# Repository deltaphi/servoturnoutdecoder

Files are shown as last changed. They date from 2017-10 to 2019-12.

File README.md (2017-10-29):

# Arudino Servo Decoder for the Motorola Protocol

* Motorola Input via INT0 (phase-correct)
* Control six Servos via the PWM outputs

# Dependencies

* Based on https://github.com/666c796e6e/LibMotorola/commit/a36dd47014a77b1eea2f04f38cabde1bba2f1c59
* Based on https://github.com/MicroBahner/MobaTools/commit/ad47b301049b6bf6d05046a2db197733567ed501

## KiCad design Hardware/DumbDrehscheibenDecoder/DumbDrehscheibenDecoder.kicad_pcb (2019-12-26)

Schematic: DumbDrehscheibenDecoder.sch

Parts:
A1: Arduino_Nano_v2.x; Arduino_Nano
C1: 470u; CP_Radial_D12.5mm_P5.00mm
D1, D2: D_Bridge_+-AA; Diode_Bridge_19.0x3.5x10.0mm_P5.0mm
D3: 1N4001; D_A-405_P7.62mm_Horizontal
H1, H2, H3, H4: MountingHole_Pad; MountingHole_3.2mm_M3_DIN965_Pad
J1, J2: Screw_Terminal_01x04; TerminalBlock_RND_205-00003_1x04_P5.00mm_Horizontal
R1, R3: 22k; R_Axial_DIN0204_L3.6mm_D1.6mm_P7.62mm_Horizontal
R2: 220; R_Axial_DIN0204_L3.6mm_D1.6mm_P7.62mm_Horizontal
SW1: SW_Push; SW_PUSH_6mm
U1: L293D; DIP-16_W7.62mm
U2: LTV-817; DIP-4_W7.62mm

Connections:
/MM_0: D1.4 (~~), D3.2, J2.2, U2.2
/MM_B: D1.3 (~~), J2.1, R1.2
/MM_Sense: A1.5 (D2), R2.1, U2.4
/MM_Vin: A1.30 (VIN), D1.1 (+)
/MOT_1Y: J1.4, U1.3
/MOT_2Y: J1.3, U1.6
/MOT_3Y: J1.1, U1.11
/MOT_4Y: J1.2, U1.14
/PWR_0: D2.4 (~~), J2.4
/PWR_B: D2.3 (~~), J2.3
/Pwr_Vin: D2.1 (+), U1.8
GND: A1.4 (GND), A1.29 (GND), C1.2, D1.2 (-), D2.2 (-), H1.1, H2.1, H3.1, H4.1, SW1.2, U1.4, U1.5, U1.12, U1.13, U2.3
unnamed: A1.6 (D3), U1.9
unnamed: A1.7 (D4), U1.7
unnamed: A1.8 (D5), U1.10
unnamed: A1.9 (D6), U1.1
unnamed: A1.10 (D7), U1.15
unnamed: A1.12 (D9), U1.2
unnamed: A1.19 (A0), R3.1, SW1.1
unnamed: D3.1, R1.1, U2.1
VCC: A1.27 (+5V), C1.1, R2.2, R3.2, U1.16

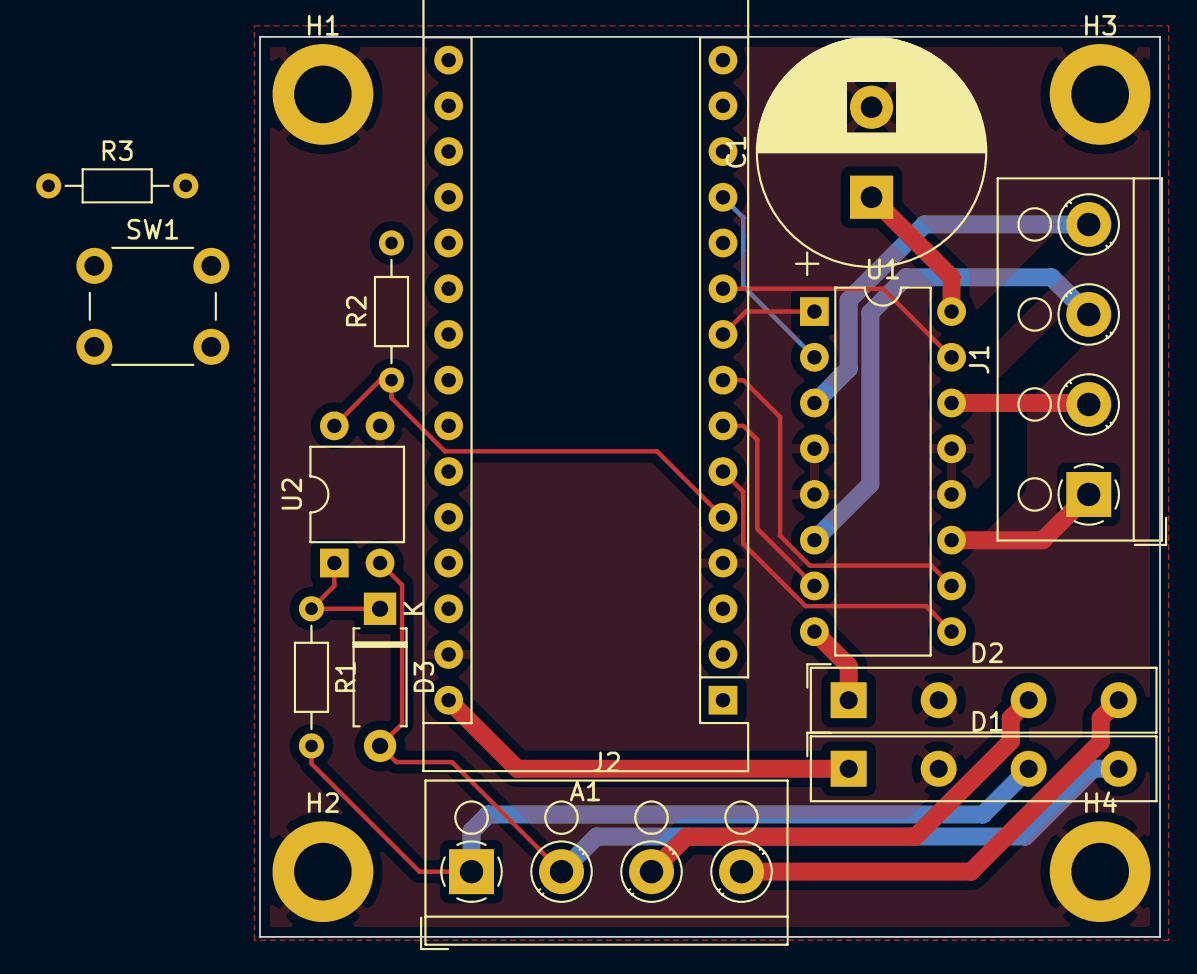
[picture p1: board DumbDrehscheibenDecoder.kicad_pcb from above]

Board: 2 copper layers, 50.0 x 50.0 mm, 17 parts (0 on the bottom side), 21 nets.

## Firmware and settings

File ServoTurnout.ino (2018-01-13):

#include <MobaTools.h>

#include <DataHandlerInterface.h>
#include <Decoder145027.h>
#include <Detect145027.h>

//Globally create a detector.
Detect145027 detector(Detect145027::TURNOUT_NOMINAL_PULSE_WIDTH_MICROS);
Decoder145027 decoder;

void handler() {

  //Do read the pin that corresponds to the interrupt as fast as possible.
  //This is machine-dependent!
  int fastReadResult = PIND & (1 << PD2);

  //Call the appropriate Method on the detector.
  if (fastReadResult != 0) {
    //state is up, must have been leading edge..
    detector.pickUpLeadingEdge();
  } else {
    //must have been trailing edge then...
    detector.pickUpTrailingEdge();
  }
}

constexpr long kRelayOnDuration_ms = 20; 

class ExampleDataHandler: public DataHandlerInterface {
public:
  const uint16_t address_;
  const uint8_t servo_pin;
  uint8_t red_angle;
  uint8_t green_angle;
  Servo8 servo_;
  int servo_pos;

  uint8_t polarize_red_pin;
  uint8_t polarize_green_pin;

  bool active = false;
  unsigned long lastActionTime;

  constexpr static uint8_t kServoSpeed = 10;

  enum TurnoutDirectionType {
    RED, GREEN
  };
  
  ExampleDataHandler(uint16_t address, uint8_t servo_pin, uint8_t red_angle, uint8_t green_angle, uint8_t polarize_red_pin, uint8_t polarize_green_pin):
    address_(address), servo_pin(servo_pin), 
    red_angle(red_angle), green_angle(green_angle),
    servo_pos(green_angle),
    polarize_red_pin(polarize_red_pin), polarize_green_pin(polarize_green_pin) {
  }

  ExampleDataHandler(uint16_t address, uint8_t servo_pin, uint8_t red_angle, uint8_t green_angle):
  address_(address), servo_pin(servo_pin),
  red_angle(red_angle), green_angle(green_angle),
  servo_pos(green_angle),
  polarize_red_pin(255), polarize_green_pin(255) {
  }

  void init() {
    servo_.attach(servo_pin, true);
    servo_.setSpeed(kServoSpeed);
    //updateServo();
    if (polarize_red_pin != 255) {
      pinMode(polarize_red_pin, OUTPUT);
      digitalWrite(polarize_red_pin, LOW);
    }
    if (polarize_green_pin != 255) {
      pinMode(polarize_green_pin, OUTPUT);
      digitalWrite(polarize_green_pin, LOW);
    }
  }

  /**
   * \brief Handle a MM message
   * 
   * \param address The address of the turnout decoder
   * \param data The addres of the Turnout (bits 0..3) and the key press mode (bit 4)
   * 
   * address is the address of a turnout decoder (switch address div 4) -> Not actually hepful? (Range: 0x1..0x4F, 0 -> Wraps around!) 0x1F is relevant
   * data contains several bits: 7 6 5 4 3 2 1 0
   *   7..5 appear to be unused
   *   4 is key pressed (set)/released (cleared)
   *   3..0 are a turnout address. Even numbers are red, odd numbers are green
   */
  void handleEvent(unsigned char decoder_address, unsigned char data) override {
    uint8_t pressed = data & 0x10;

    if (pressed) {
      char buf[24];
      uint8_t gerade = (data & 0x02);
      data &= 0x0F;
      data >>= 2;

      uint16_t turnout_address = (static_cast<uint16_t>(decoder_address) << 2) | data;
      if (decoder_address == 0) {
        turnout_address += 320;
      }
      turnout_address -= 3;
    
      if (turnout_address == address_) {
        Serial.print(F("Turnout "));
        Serial.print(turnout_address, DEC);
        Serial.print(F(" set to "));
        if (gerade) {
          Serial.print(F(" green"));
        } else {
          Serial.print(F(" red"));
        }
        Serial.println();

        setLed(gerade);
      }
    }
  }

  void setLed(uint8_t data) {
    //data = data & 0x02;
    if (data) {
      servo_pos = green_angle;
      polarize(RED);
    } else {
      servo_pos = red_angle;
      polarize(GREEN);
    }
    updateServo();
  }

  void polarize(TurnoutDirectionType dir) {
    if (dir == RED) {
      if (polarize_green_pin != 255) {
        Serial.println(F(" Polarize GREEN LOW"));
        digitalWrite(polarize_green_pin, LOW);
      }
      if (polarize_red_pin != 255) {
        Serial.println(F(" Polarize RED HIGH"));
        digitalWrite(polarize_red_pin, HIGH);
      }
    } else {
      if (polarize_red_pin != 255) {
        Serial.println(F(" Polarize RED LOW"));
        digitalWrite(polarize_red_pin, LOW);
      }
      if (polarize_green_pin != 255) {
        Serial.println(F(" Polarize GREEN HIGH"));
        digitalWrite(polarize_green_pin, HIGH);
      }
    }
    lastActionTime = millis();
    active = true;
  }

  void updateServo() {
    servo_.write(servo_pos);
  }

  void checkTimeout() {
    unsigned long now = millis();
    if (active && (now - lastActionTime) >= kRelayOnDuration_ms) {
      handleTimeout();
    }
  }

  void handleTimeout() {
    Serial.println(F("Timeout"));
    active = false;
    if (polarize_red_pin != 255) {
      digitalWrite(polarize_red_pin, LOW);
    }
    if (polarize_green_pin != 255) {
      digitalWrite(polarize_green_pin, LOW);
    }
  }
};

constexpr uint8_t kNumDataHandlers = 6;
uint8_t servo_index;

/* Left board */
// addr, pin, red, green
ExampleDataHandler handlers[kNumDataHandlers] = {
  ExampleDataHandler(100, 9, 75, 120), // done
  ExampleDataHandler(101, 10, 55, 110), // done
  ExampleDataHandler(102, 11, 50, 125), // done
  ExampleDataHandler(103, A5, 40, 100, 5, 6), // done
  ExampleDataHandler(104, A4, 85, 150, 7, 8),
  ExampleDataHandler(105, A3, 70, 140)  // N/A
};
/**/

/* Right board
// addr, pin, red, green
ExampleDataHandler handlers[kNumDataHandlers] = {
  ExampleDataHandler(109, 9, 30, 115), // done   - Turnout 9
  ExampleDataHandler(2, 10, 55, 110), // pin broken
  ExampleDataHandler(106, 11, 50, 100), // done                 - Turnout 6
  ExampleDataHandler(107, A5, 105, 60, 5, 6), // done           - Turnout 7
  ExampleDataHandler(108, A4, 60, 120, 7, 8), // done           - Turnout 8
  ExampleDataHandler(110, A3, 110, 50)  // done                - Turnout 10
};
/**/

//The setup function is called once at startup of the sketch
void setup() {
  Serial.begin(115200);
  Serial.println("Initializing!");

  pinMode(2, INPUT);

  attachInterrupt(0, &handler, CHANGE);
  //Do not use two interrupt handlers on the same pin!
  //(RISING, FALLING)... That didn't work for me.
  //Use CHANGE instead and do a fast read in the interrupt handler
  //to tell leading from trailing edges!

  for (uint8_t i = 0; i < kNumDataHandlers; ++i) {
    handlers[i].init();
    decoder.addHandler(&handlers[i]);
  }
  servo_index = kNumDataHandlers;
  dumpServos();
}

void dumpServos() {
  for (uint8_t i = 0; i < kNumDataHandlers; ++i) {
    Serial.print(", Servo ");
    Serial.print(i+1, DEC);
    Serial.print(": ");
    Serial.print(handlers[i].servo_pos, DEC);
  }
  Serial.println(".");
}

String readString;

// The loop function is called in an endless loop
void loop() {
  if (detector.available()) {
    unsigned char* datagram = detector.getCurrentDatagram();

/*
    Serial.print(F("Received Data: 0x"));
    for (int i = 0; i < 18; i++) {
      Serial.print((int) datagram[i], HEX);
      Serial.print(" ");
    }
    Serial.println();
*/
    decoder.decodeDatagram(datagram);
  }

  //Serial.write("\n");
  if (Serial.available() > 0) {
    char c = Serial.read();

    if (c == '\n') {
      Serial.write("Read String: '");
      Serial.print(readString);
      
      int value = readString.toInt();

      if (servo_index == kNumDataHandlers) {
        // No servo selected
        if (value <= kNumDataHandlers) {
          // Switch to servo control mode
          servo_index = value - 1;
        } else {
          // Explicit turnout toggle mode. Addresses are 11/12, 21/22, 31/32, 41/42, 51/52, 61/62
          // odd is green
          uint8_t turnout = value / 10;
          if (0 < turnout && turnout <= kNumDataHandlers) {
            turnout -= 1;

           uint8_t gerade = value % 2;
           handlers[turnout].setLed(gerade);
          }
        }
      } else {
        // Servo selected
        if (value > 180) {
          // Invalid servo angle, switch to no-servo-selected mode
          servo_index = kNumDataHandlers;
        } else {
          handlers[servo_index].servo_pos = value;
          handlers[servo_index].updateServo();
        }
      }
      
      Serial.write("', Servo ");
      Serial.print(servo_index + 1, DEC);
      Serial.write(" at position ");
      if (servo_index < kNumDataHandlers) {
        Serial.println(handlers[servo_index].servo_pos, DEC);
      } else {
        Serial.println("N/A.");
      }
      
      readString = "";
      dumpServos();
    } else {
      readString += c;
    }
  }

  for (uint8_t i = 0; i < kNumDataHandlers; ++i) {
    handlers[i].checkTimeout();
  }

}

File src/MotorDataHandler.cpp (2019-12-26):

#include "MotorDataHandler.h"

void MotorDataHandler::setPins(Pin_t motorPin1, Pin_t motorPin2,
                               Pin_t relayHighPin, Pin_t relayLowPin) {
  this->motorPin1 = motorPin1;
  pinMode(this->motorPin1, OUTPUT);
  analogWrite(this->motorPin1, 0);

  this->motorPin2 = motorPin2;
  pinMode(this->motorPin2, OUTPUT);
  analogWrite(this->motorPin2, 0);

  this->relayHighPin = relayHighPin;
  pinMode(this->relayHighPin, OUTPUT);
  digitalWrite(relayHighPin, LOW);

  this->relayLowPin = relayLowPin;
  pinMode(this->relayLowPin, OUTPUT);
  digitalWrite(relayLowPin, LOW);
}

void MotorDataHandler::setSpeed(Speed_t newSpeed) {
  Pwm_t lowValue = 0;
  Pwm_t highValue;
  uint8_t relayValue = LOW;

  switch (newSpeed) {
    case Speed_t::OFF:
      highValue = kPwmOff;
      relayValue = HIGH;
      break;
    case Speed_t::SLOW:
      highValue = kPwmSlow;
      relayValue = HIGH;
      break;
    case Speed_t::FULL:
      highValue = kPwmFull;
      relayValue = LOW;
      break;
  }

  if (relayValue == LOW) {
    digitalWrite(relayHighPin, relayValue);
  }

  if (direction == Direction_t::RIGHT) {
    analogWrite(motorPin1, lowValue);
    analogWrite(motorPin2, highValue);
  } else {
    analogWrite(motorPin1, highValue);
    analogWrite(motorPin2, lowValue);
  }

  if (relayValue == HIGH) {
    // Briefly wait for the PWM to apply before switching the relay
    delay(10);
    digitalWrite(relayHighPin, relayValue);
  }

  speed = newSpeed;
  lastSpeedChange = millis();
}

void MotorDataHandler::handleEvent(unsigned char address, unsigned char data) {
  /*
  Serial.print(F("Received apacket for "));
  Serial.print((uint8_t)address, DEC);
  Serial.print(F(" with data 0x"));
  Serial.print(data, BIN);
  Serial.println(".");
  */
  uint8_t pressed = data & 0x10;
  if (!pressed) {
    return;
  }

  uint8_t gerade = (data & 0x02);
  data &= 0x0F;
  data >>= 2;

  uint16_t turnout_address = (static_cast<uint16_t>(address) << 2) | data;
  // Possibly missing a warparound from 0 to 320. Then again, we can't handle
  // 320 in an unsigned char anyways.
  if (address == 0) {
    turnout_address += 320;
  }
  turnout_address -= 3;
  /*
  Serial.print("Decoded address: ");
  Serial.println(turnout_address, DEC);
  */
  if (turnout_address == directionAddress) {
    Serial.print(F("Setting Motor direction to "));
    if (gerade) {
      Serial.println("LEFT.");
      setDirection(Direction_t::LEFT);
    } else {
      Serial.println("RIGHT.");
      setDirection(Direction_t::RIGHT);
    }
  } else if (turnout_address == relayAddress) {
    if (gerade) {
      // make it go
      Serial.println(F("Activating relay. Setting Motor speed to FULL."));
      setSpeed(Speed_t::FULL);
    } else {
      Serial.println(F("Deactivating relay. Setting Motor speed to SLOW."));
      setSpeed(Speed_t::SLOW);
    }
  }
}

void MotorDataHandler::setDirection(Direction_t direction) {
  if (this->direction != direction) {
    if (speed != Speed_t::OFF) {
      // There is a direction change in full flight going on. Stop the motor
      // first.
      setSpeed(Speed_t::OFF);
      delay(100);
    }
    this->direction = direction;
  }
}

void MotorDataHandler::checkTimeout() {
  if (speed != Speed_t::SLOW) {
    // only slow has a timeout value
    return;
  }

  unsigned int now = millis();
  if (now - lastSpeedChange > kLowSpeedTimeout) {
    Serial.println(F("Low Timeout expired. Setting Motor speed to OFF."));
    setSpeed(Speed_t::OFF);
  }
}

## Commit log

2017-10-22 Added decoder and initial Servo test
2017-10-28 Upgrade to 6 Servos, new default values
2017-10-31 First board working
2018-01-06 Initial work on the second Turnout board
2018-01-06 Adjusted values for left board
2019-12-02 Removed Servo functionality. Now 'polarization' only.
2019-12-03 Update .gitignore
    Now Supports KiCAD
2019-12-03 WIP: Initial version of PCB
    [DumbDrehscheibenDecoder.kicad_pcb, DumbDrehscheibenDecoder.sch]
2019-12-26 Added controller that works based on motor driver rather than relays
2019-12-26 Updated the PCB
    [DumbDrehscheibenDecoder.kicad_pcb, DumbDrehscheibenDecoder.sch]
